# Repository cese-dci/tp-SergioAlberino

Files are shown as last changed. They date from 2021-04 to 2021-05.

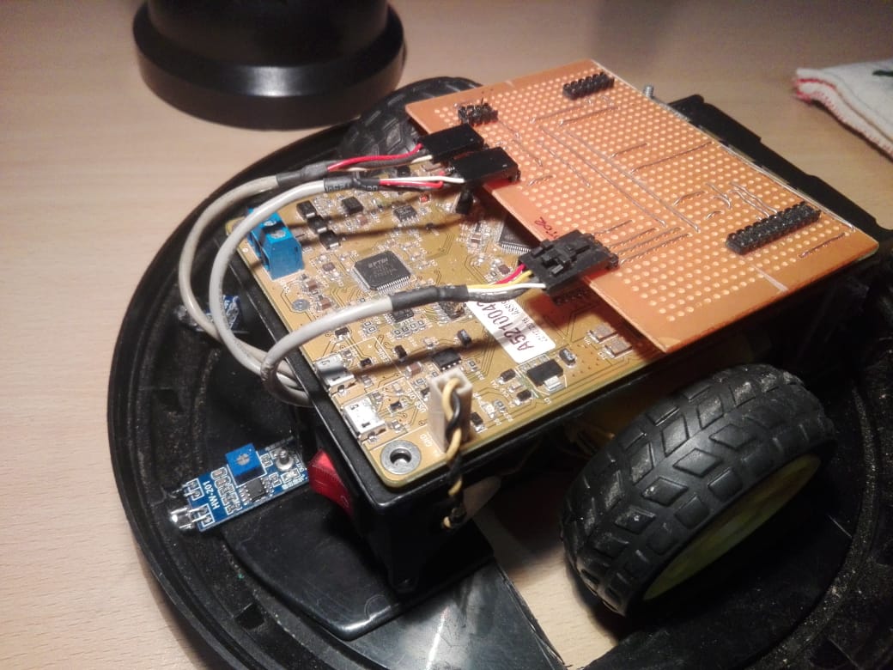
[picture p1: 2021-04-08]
Poncho_rUVot/Imágenes/Fotos/Prototipo de prueba/Primera versión en placa experimental.jpeg

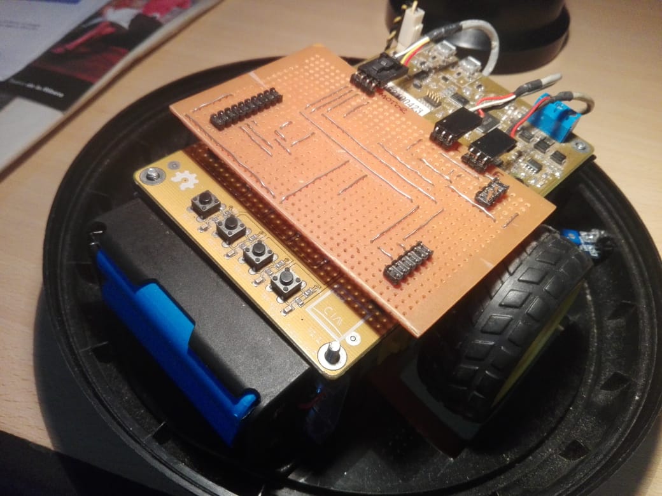
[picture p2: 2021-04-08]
Poncho_rUVot/Imágenes/Fotos/Prototipo de prueba/Primera versión en placa experimental2.jpeg

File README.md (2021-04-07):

# tp-SergioAlberino
tp-SergioAlberino created by GitHub Classroom
Materia: Diseño de Circuitos Impresos. Especialización de Sistemas Embebidos (FIUBA)

Poncho distribuidor para Robot rUVot
====================================

Placa para el robot "rUVot". Se trata de un pequeño robot movil para inspección y desinfección por UV. El mismo tiene un funcionamiento autónomo o puede manejarse en modo teleoperado por Bluetooth

La finalidad de esta Placa es la de cumplir funciones de  "distribuidora" de los pines de la EDU-CIA para interconectar los sensores y actuadores del robot de inspección y desinfección por UV. 
Permite conectar todo en forma ordenada y modular. 
El dongle Bluetooth se conecta a esta placa.

URL: (URL en la wiki de la CIAA)
FUNCIÓN: Placa "distribuidora" de los pines de la EDU-CIA para interconectar los sensores y actuadores de un robot de inspección y desinfección por UV

AUTORES/INSTITUCIONES: Sergio Alberino / GIAR - UTN.FRBA

DOCENTE: Diego Brengi

REVISOR: Pablo D. Folino

Año: 2021

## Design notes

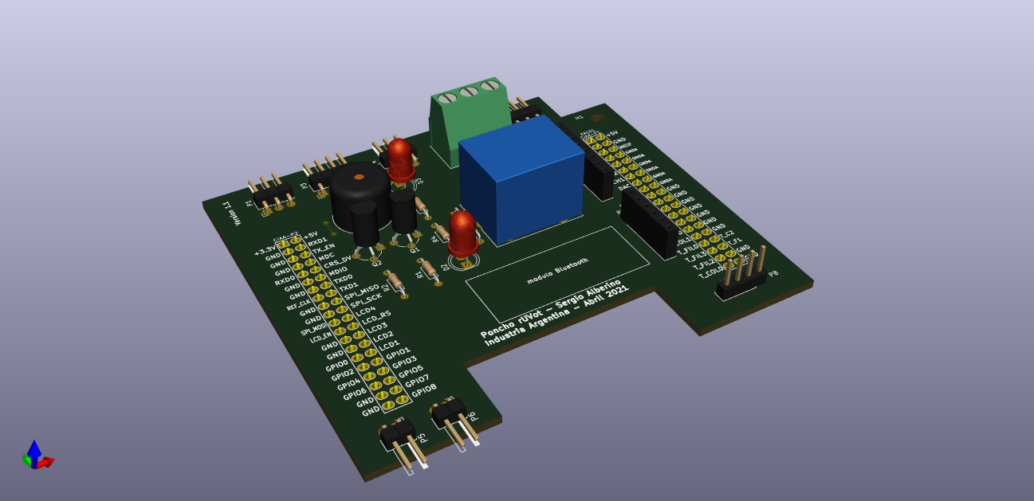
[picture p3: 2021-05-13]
Poncho_rUVot/Imágenes/3D/Poncho_rUVotvista34.png

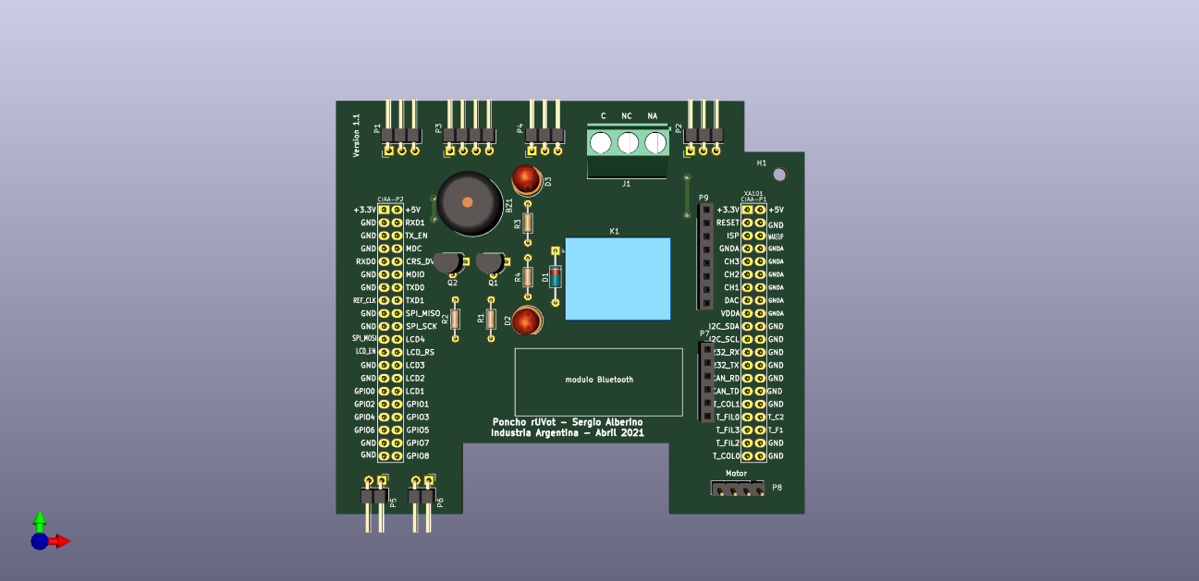
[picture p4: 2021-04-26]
Poncho_rUVot/Imágenes/3D/Poncho_rUVotvista4.png

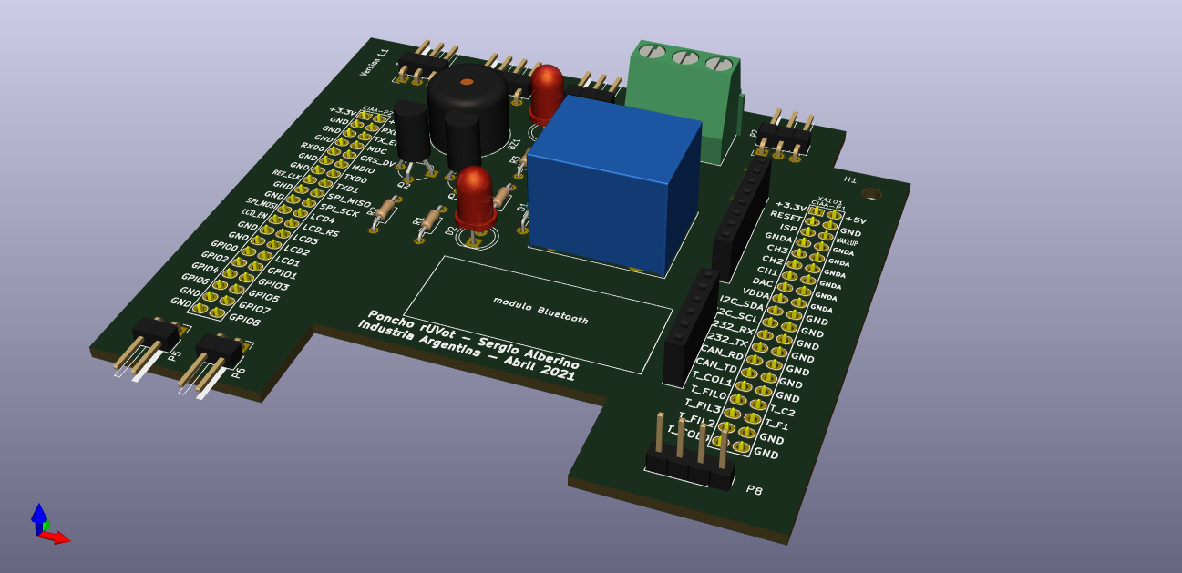
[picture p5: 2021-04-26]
Poncho_rUVot/Imágenes/3D/Poncho_rUVotvista5.png

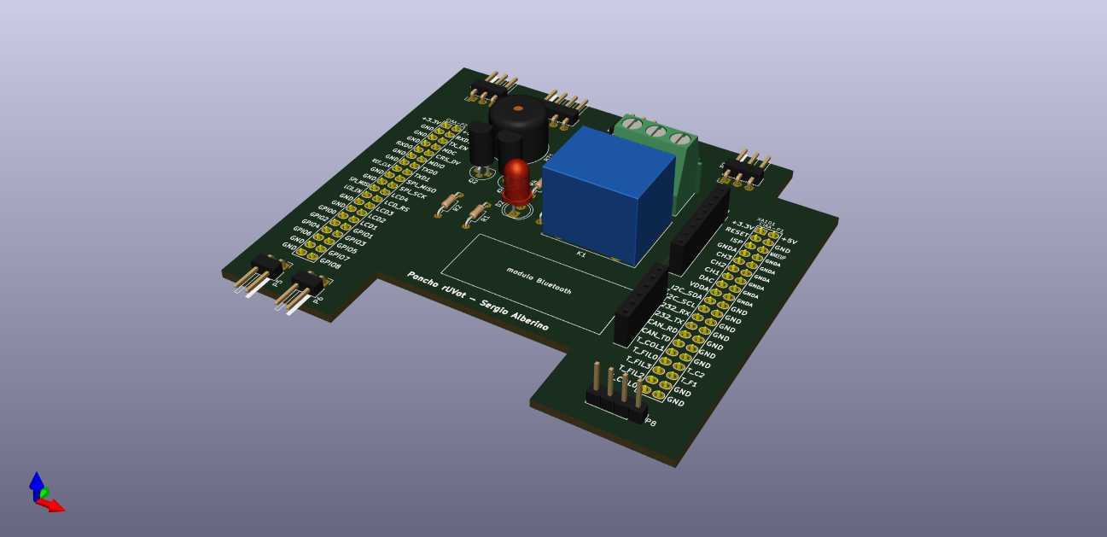
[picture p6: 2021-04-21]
Poncho_rUVot/Imágenes/3D/Poncho_rUVotvista2.png

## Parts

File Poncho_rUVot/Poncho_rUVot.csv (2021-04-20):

Id | Designator | Package | Quantity | Designation | Supplier and ref
1 | XA101 | Conn_Poncho_SinBorde | 1 | Conn_Poncho2P_2x_20x2
2 | P2,P4,P1 | PinHeader_1x03_P2.54mm_Horizontal | 3 | Conn_01x03
3 | Q2,Q1 | TO-92L | 2 | BC548
4 | P8 | PinHeader_1x04_P2.54mm_Vertical | 1 | Conn_01x04
5 | R4 | R_Axial_DIN0204_L3.6mm_D1.6mm_P7.62mm_Horizontal | 1 | 470
6 | R2,R1 | R_Axial_DIN0204_L3.6mm_D1.6mm_P7.62mm_Horizontal | 2 | 220
7 | P9 | PinSocket_1x08_P2.54mm_Vertical | 1 | Conn_01x08
8 | P7 | PinSocket_1x06_P2.54mm_Vertical | 1 | Conn_01x06
9 | P6,P5 | PinHeader_1x02_P2.54mm_Horizontal | 2 | Conn_01x02
10 | P3 | PinHeader_1x04_P2.54mm_Horizontal | 1 | Conn_01x04
11 | K1 | Relay_SPDT_SANYOU_SRD_Series_Form_C | 1 | SANYOU_SRD_Form_C
12 | J1 | TerminalBlock_Phoenix_MKDS-1,5-3-5.08_1x03_P5.08mm_Horizontal | 1 | Screw_Terminal_01x03
13 | D2 | LED_D5.0mm | 1 | LED
14 | D1 | D_DO-35_SOD27_P10.16mm_Horizontal | 1 | 1N4148
15 | BZ1 | Buzzer_12x9.5RM7.6 | 1 | Buzzer

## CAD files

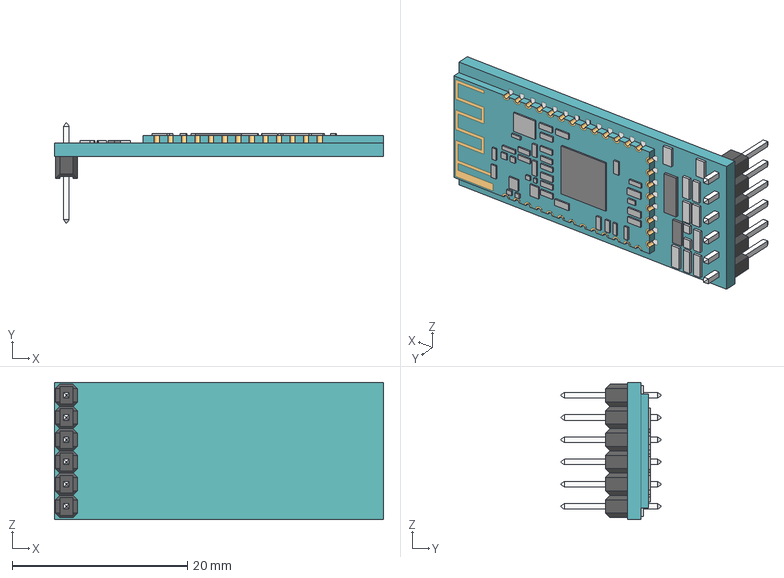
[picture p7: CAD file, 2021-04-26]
Poncho_rUVot/shapes3D/hc-series-1.snapshot.7/HC-SERIES.stp
37.6 x 11.4 x 15.7 mm
Pin Header 6 x 1 TH 2.54mm Pitch x 12

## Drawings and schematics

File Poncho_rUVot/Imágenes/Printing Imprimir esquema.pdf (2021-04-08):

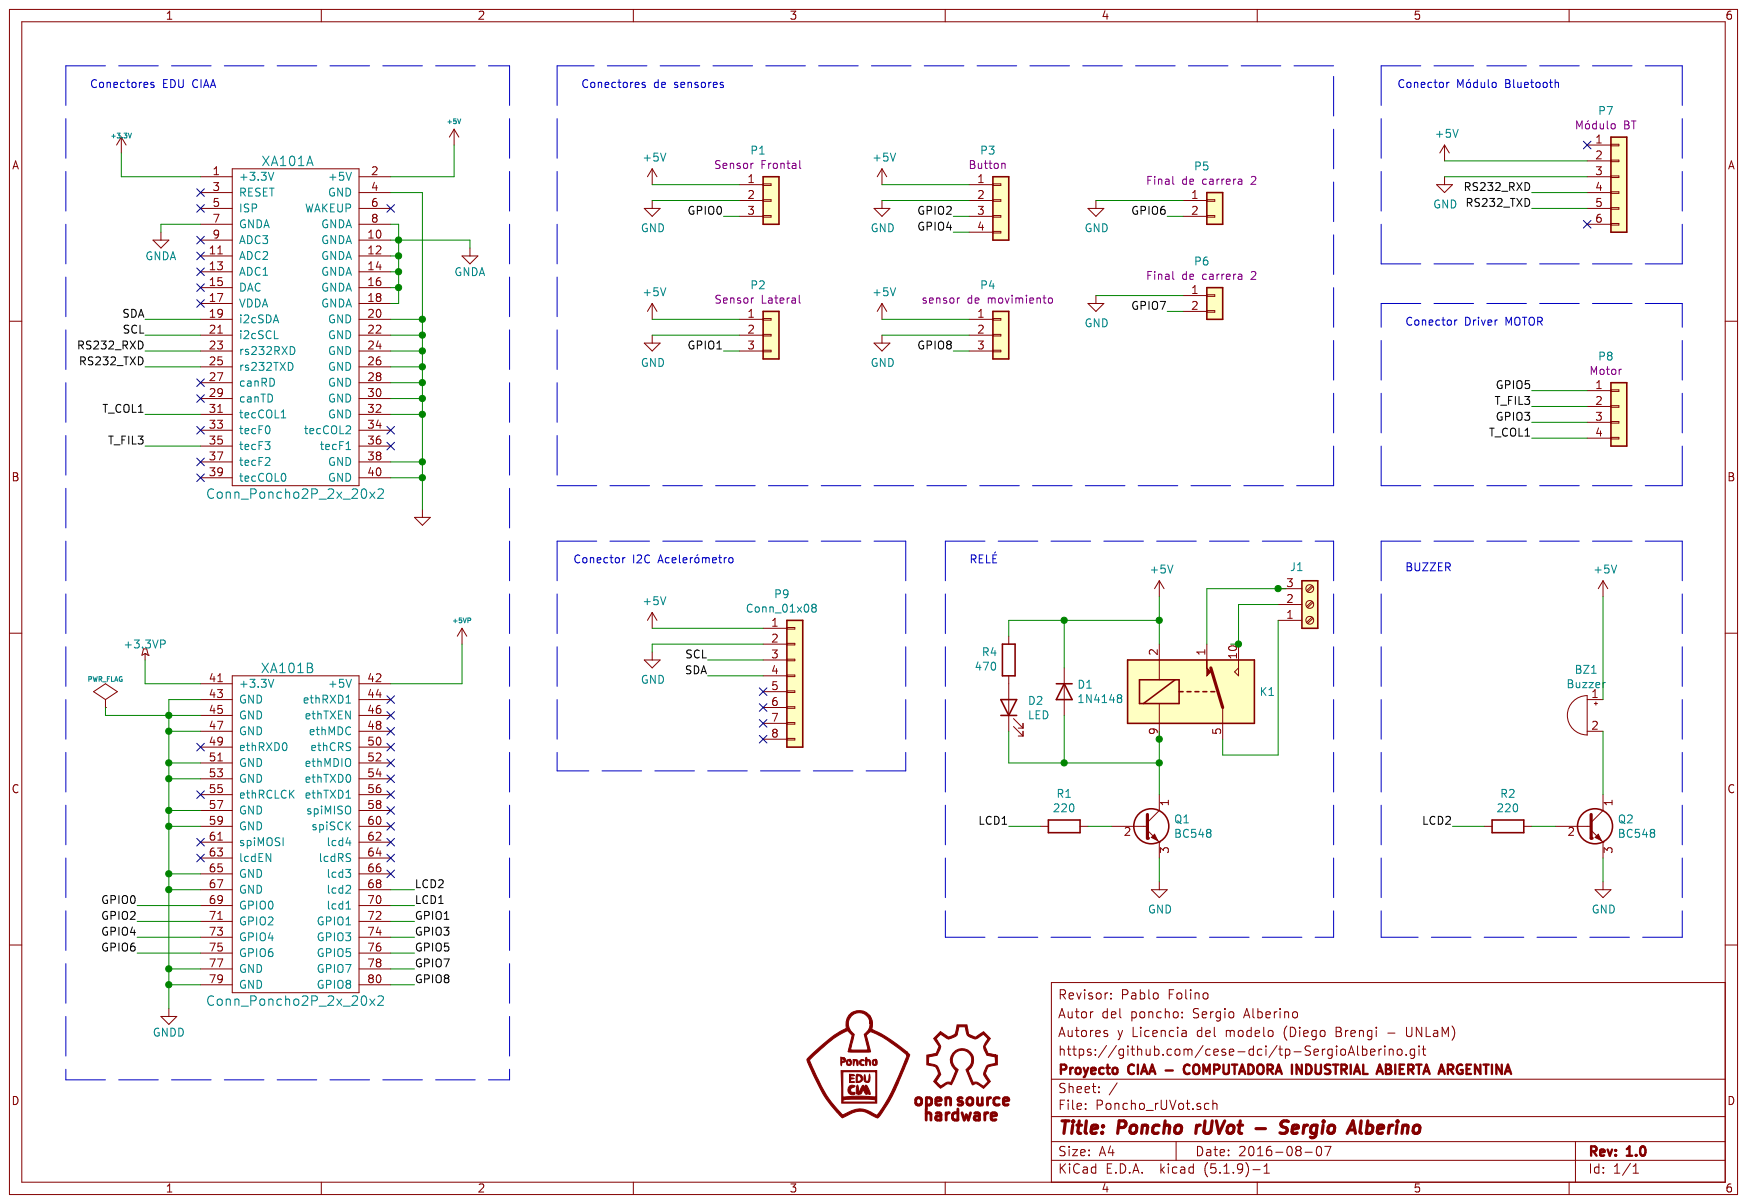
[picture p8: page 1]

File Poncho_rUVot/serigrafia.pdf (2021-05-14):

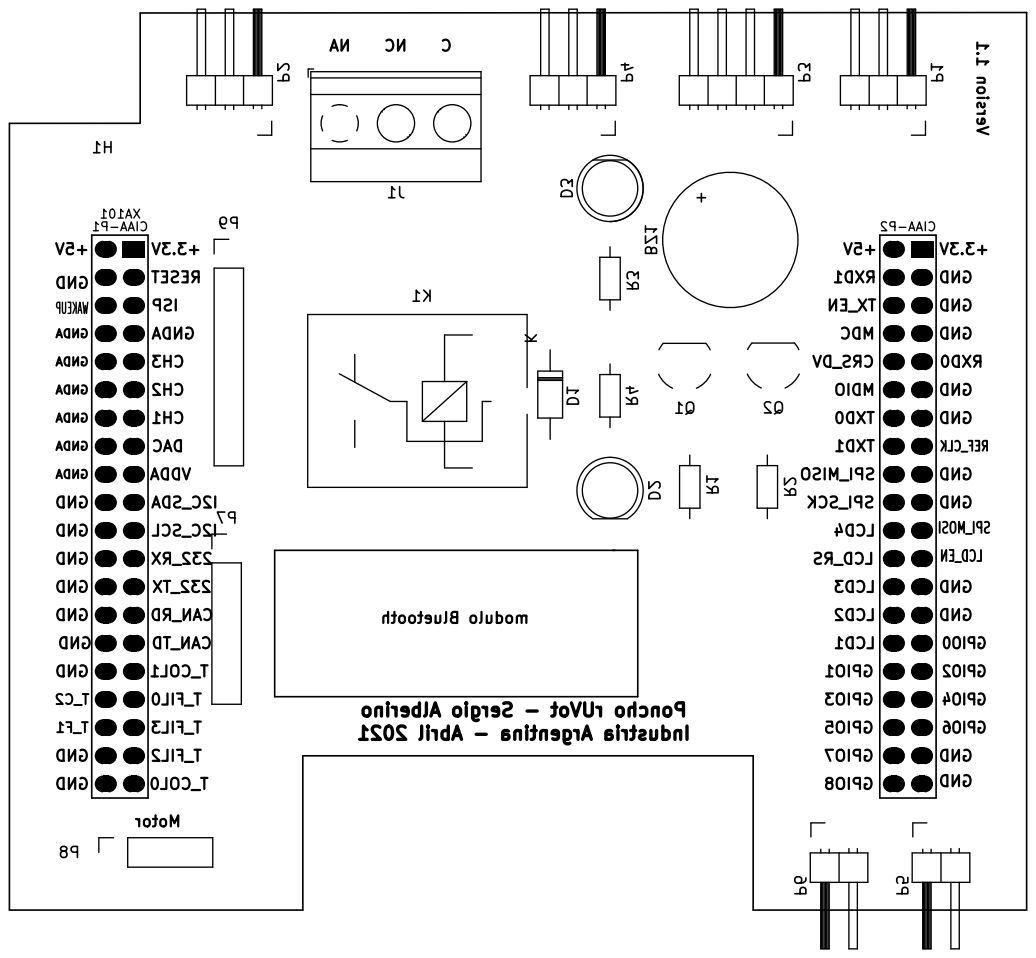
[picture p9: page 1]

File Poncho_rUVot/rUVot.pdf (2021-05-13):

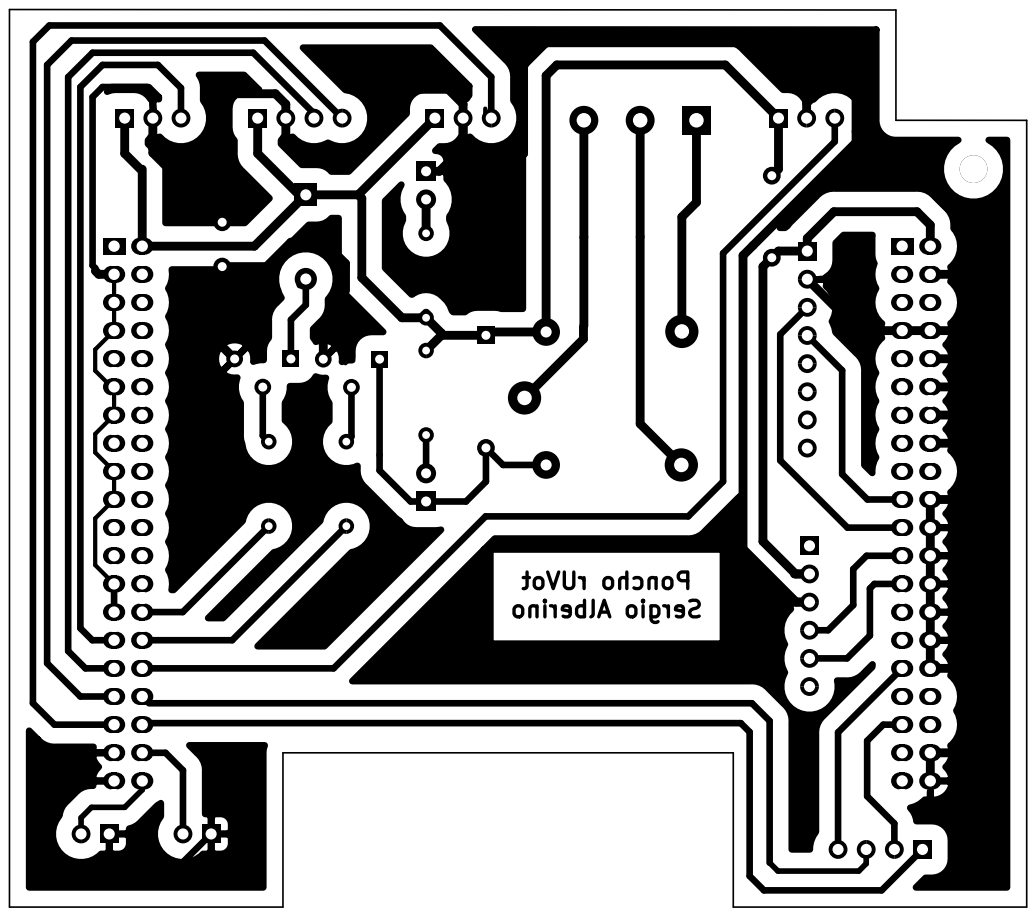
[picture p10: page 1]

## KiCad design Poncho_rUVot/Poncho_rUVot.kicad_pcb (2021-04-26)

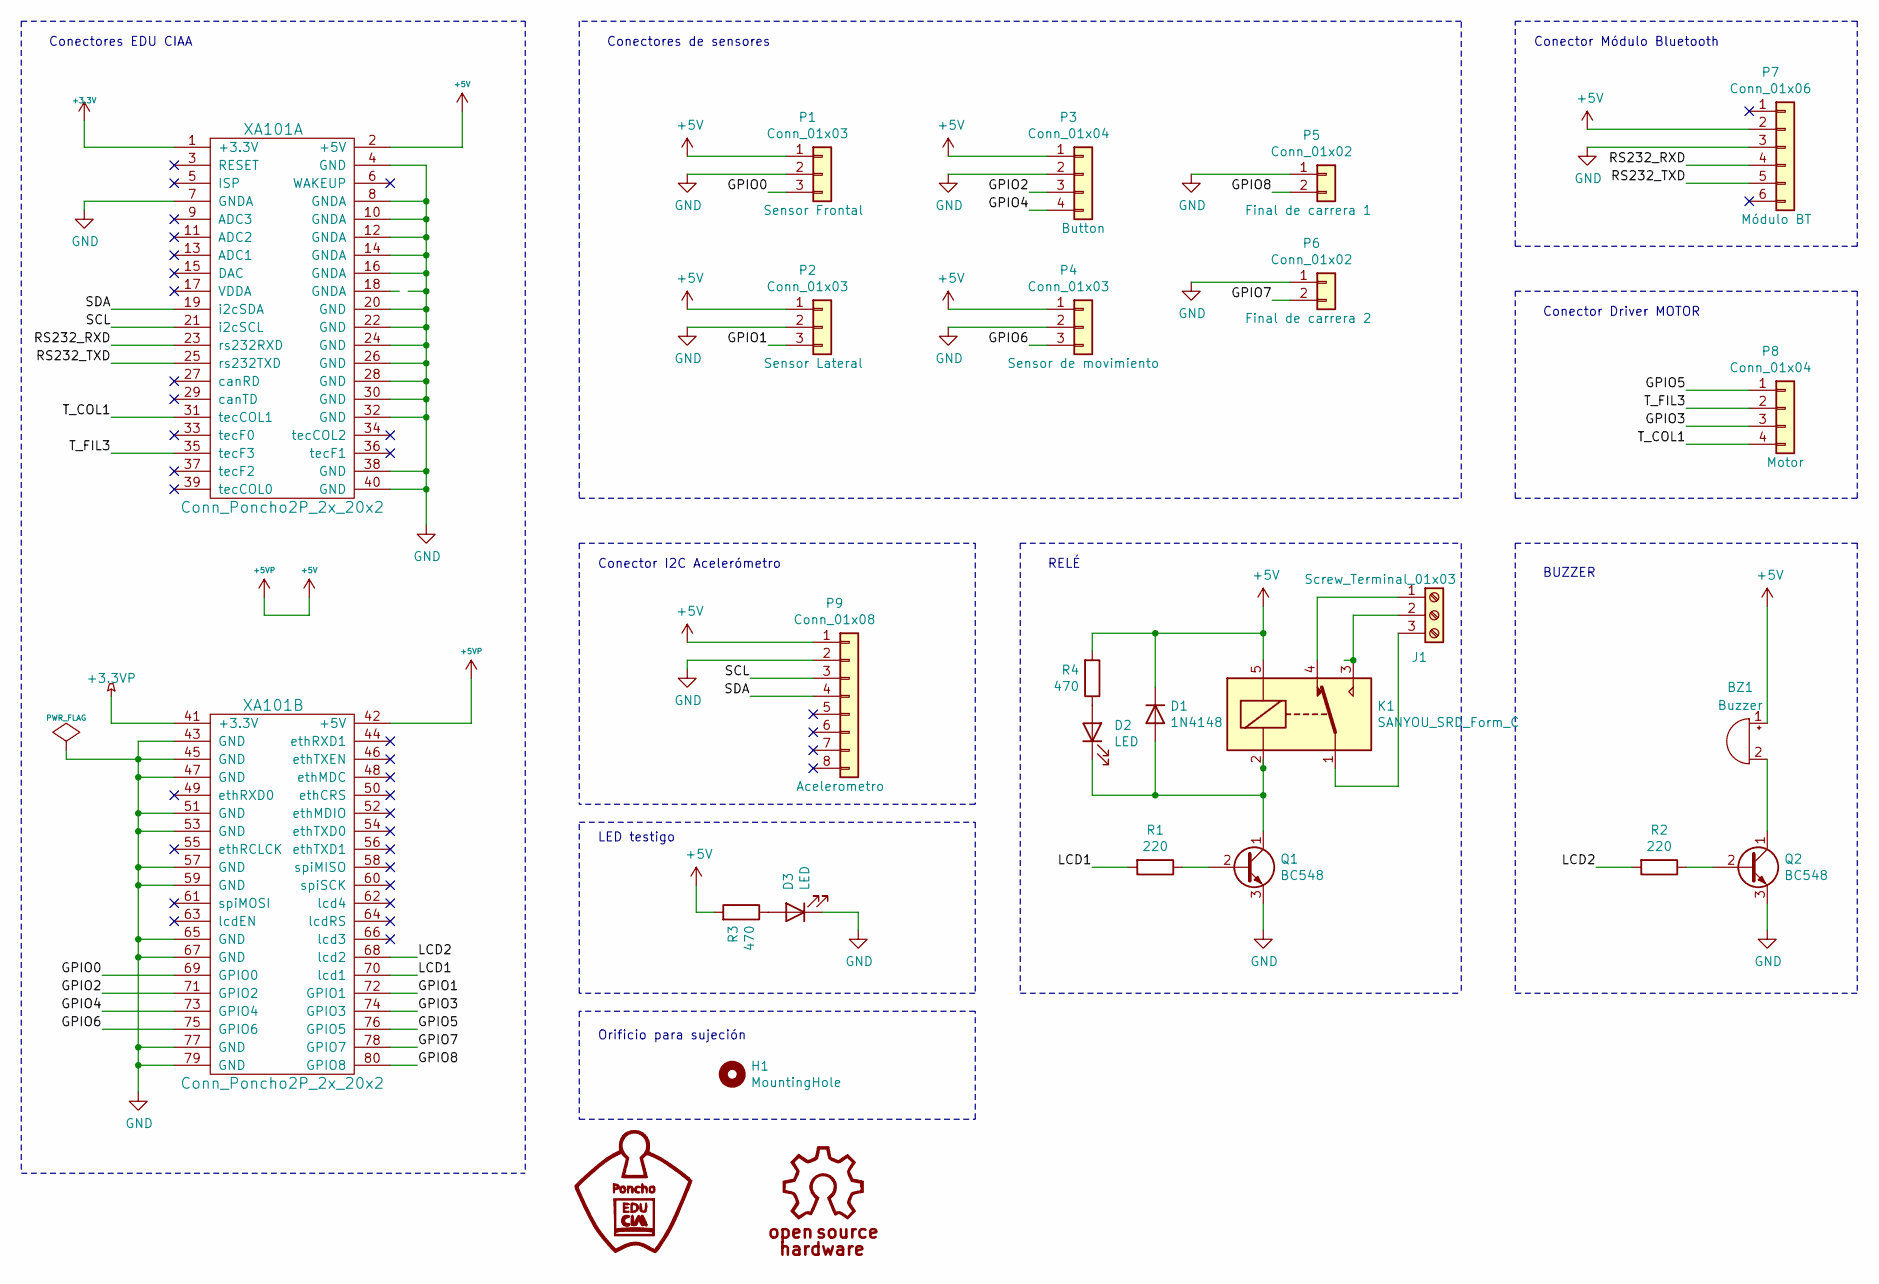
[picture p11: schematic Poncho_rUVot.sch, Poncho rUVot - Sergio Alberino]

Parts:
BZ1: Buzzer; Buzzer_12x9.5RM7.6
D1: 1N4148; D_DO-35_SOD27_P10.16mm_Horizontal
D2, D3: LED; LED_D5.0mm
H1: MountingHole; MountingHole_2.5mm
J1: Screw_Terminal_01x03; TerminalBlock_Phoenix_MKDS-1,5-3-5.08_1x03_P5.08mm_Horizont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
K1: SANYOU_SRD_Form_C; Relay_SPDT_SANYOU_SRD_Series_Form_C
P1, P2, P4: Conn_01x03; PinHeader_1x03_P2.54mm_Horizontal
P3: Conn_01x04; PinHeader_1x04_P2.54mm_Horizontal
P5, P6: Conn_01x02; PinHeader_1x02_P2.54mm_Horizontal
P7: Conn_01x06; PinSocket_1x06_P2.54mm_Vertical
P8: Conn_01x04; PinHeader_1x04_P2.54mm_Vertical
P9: Conn_01x08; PinSocket_1x08_P2.54mm_Vertical
Q1, Q2: BC548; TO-92L_Wide
R1, R2: 220; R_Axial_DIN0204_L3.6mm_D1.6mm_P7.62mm_Horizontal
R3, R4: 470; R_Axial_DIN0204_L3.6mm_D1.6mm_P7.62mm_Horizontal
XA101: Conn_Poncho2P_2x_20x2; Conn_Poncho_SinBorde; Digikey# 952-1387-ND

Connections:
+3.3VP: XA101.41 (+3.3V)
+3V3: XA101.1 (+3.3V)
+5V: BZ1.1 (-), D1.1 (K), K1.5, P1.1, P2.1, P3.1, P4.1, P7.2, P9.1, R3.2, R4.2, XA101.2 (+5V), XA101.42 (+5V)
/GPIO0: P1.3, XA101.69 (GPIO0)
/GPIO1: P2.3, XA101.72 (GPIO1)
/GPIO2: P3.3, XA101.71 (GPIO2)
/GPIO3: P8.3, XA101.74 (GPIO3)
/GPIO4: P3.4, XA101.73 (GPIO4)
/GPIO5: P8.1, XA101.76 (GPIO5)
/GPIO6: P4.3, XA101.75 (GPIO6)
/GPIO7: P6.2, XA101.78 (GPIO7)
/GPIO8: P5.2, XA101.80 (GPIO8)
/LCD1: R1.2, XA101.70 (lcd1)
/LCD2: R2.2, XA101.68 (lcd2)
/RS232_RXD: P7.4, XA101.23 (rs232RXD)
/RS232_TXD: P7.5, XA101.25 (rs232TXD)
/SCL: P9.3, XA101.21 (i2cSCL)
/SDA: P9.4, XA101.19 (i2cSDA)
/T_COL1: P8.4, XA101.31 (tecCOL1)
/T_FIL3: P8.2, XA101.35 (tecF3)
GND: D3.1 (K), P1.2, P2.2, P3.2, P4.2, P5.1, P6.1, P7.3, P9.2, Q1.3 (E), Q2.3 (E), XA101.4 (GND), XA101.7 (GNDA), XA101.8 (GNDA), XA101.10 (GNDA), XA101.12 (GNDA), XA101.14 (GNDA), XA101.16 (GNDA), XA101.20 (GND), XA101.22 (GND), XA101.24 (GND), XA101.26 (GND), XA101.28 (GND), XA101.30 (GND), XA101.32 (GND), XA101.38 (GND), XA101.40 (GND), XA101.43 (GND), XA101.45 (GND), XA101.47 (GND), XA101.51 (GND), XA101.53 (GND), XA101.57 (GND), XA101.59 (GND), XA101.65 (GND), XA101.67 (GND), XA101.77 (GND), XA101.79 (GND)
unnamed: BZ1.2 (+), Q2.1 (C)
unnamed: D1.2 (A), D2.1 (K), K1.2, Q1.1 (C)
unnamed: D2.2 (A), R4.1
unnamed: D3.2 (A), R3.1
unnamed: J1.1, K1.4
unnamed: J1.2, K1.3
unnamed: J1.3, K1.1
unnamed: Q1.2 (B), R1.1
unnamed: Q2.2 (B), R2.1

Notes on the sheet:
BUZZER
Conector Módulo Bluetooth
RELÉ
Conector Driver MOTOR
Conector I2C Acelerómetro
Conectores EDU CIAA
Conectores de sensores
LED testigo
Orificio para sujeción

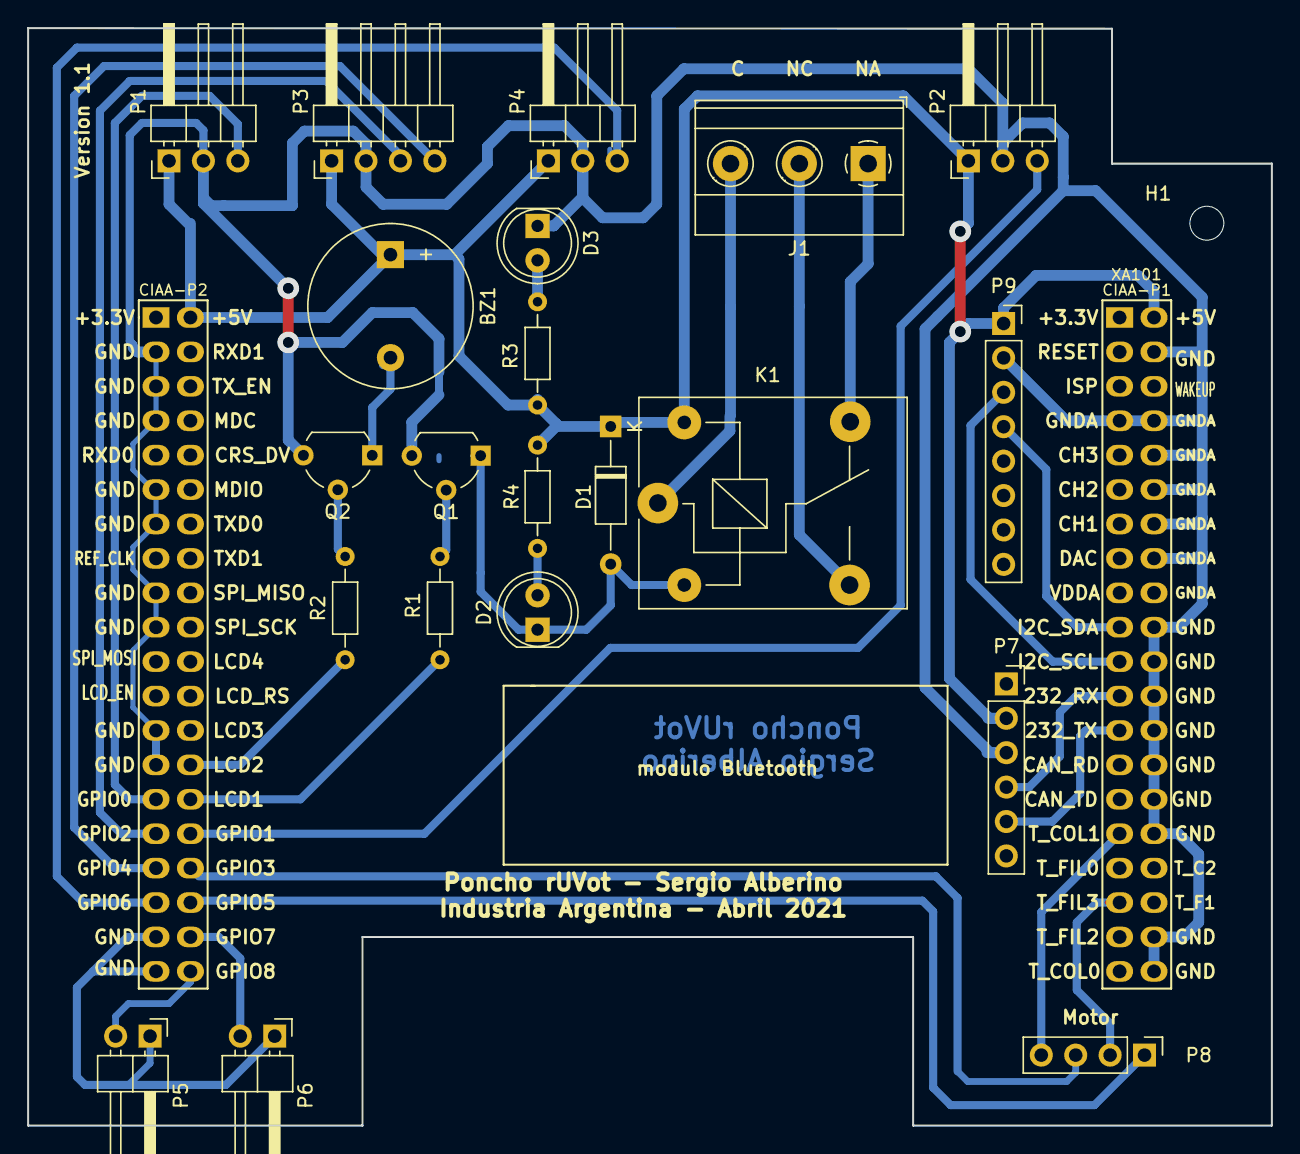
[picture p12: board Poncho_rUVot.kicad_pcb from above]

Board: 2 copper layers, 91.8 x 81.0 mm, 23 parts (0 on the bottom side), 28 nets.

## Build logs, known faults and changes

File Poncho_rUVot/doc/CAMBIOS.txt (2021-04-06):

Historial de cambios realizados 
================================

* Fecha: 	23/03/2021
* Autores: 	Sergio Alberino
* Archivos: 	Proyecto rUVot
* Descripción: 	Se parte del Modelo básico de Poncho en: 
               	https://github.com/ciaa/Ponchos/tree/master/Basico

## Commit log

2021-04-06 Comit inicial
    [Poncho_rUVot-2021-04-05-16-24-41.sch, Poncho_rUVot.kicad_pcb, Poncho_rUVot.sch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]
2021-04-06 actualizo esquematico
    [Poncho_rUVot.sch]
2021-04-08 actualización
    [1.4.Plantilla de revisión de PCBs - Folino.xlsx, Poncho_rUVot.sch]
2021-04-08 Se completa planilla de revisión
    [1.4.Plantilla de revisión de PCBs - Folino.xlsx]
2021-04-09 Se elimina erro electrico en esquematico
    [1.4.Plantilla de revisión de PCBs - Alberinol.xlsx, Poncho_rUVot.csv, Poncho_rUVot.sch]
2021-04-16 Se hacen correciones indicadas en el esquematico
    [Poncho_rUVot.sch]
2021-04-20 Se agrega el PCB
    [Poncho_rUVot.kicad_pcb, Poncho_rUVot.sch]
2021-04-20 Se agregan detalles
    [Poncho_rUVot.csv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]
2021-04-21 Correcciones de tamaño de pista
    [Poncho_rUVot.kicad_pcb]
2021-04-22 Correcciones de detalles
    [Poncho_rUVot.kicad_pcb, Poncho_rUVot.sch]
2021-04-22 Agrego Revisión Folino PCB
    [1.4.Plantilla de revisión de PCBs - Folino.xlsx]
2021-04-22 Correcciones sugeridas
    [Poncho_rUVot.kicad_pcb]
2021-04-25 Correcciones de PCB sugeridas
    [Poncho_rUVot.kicad_pcb, Poncho_rUVot.sch]
2021-04-25 Se elimina un puente
    [Poncho_rUVot.kicad_pcb, Poncho_rUVot.sch]
2021-04-26 se agrega led testigo
    [HC-SERIES.stp, Poncho_rUVot.kicad_pcb, Poncho_rUVot.sch]
2021-05-17 Se agregan fotos del proceso de la placa

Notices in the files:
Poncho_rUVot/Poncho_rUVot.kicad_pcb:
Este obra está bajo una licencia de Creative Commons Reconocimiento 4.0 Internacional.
